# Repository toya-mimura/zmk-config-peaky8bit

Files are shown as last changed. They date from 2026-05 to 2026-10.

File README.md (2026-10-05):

# Peaky 8-bit

A handheld, wireless, 8-key chording keyboard for typing on the go — even while walking.

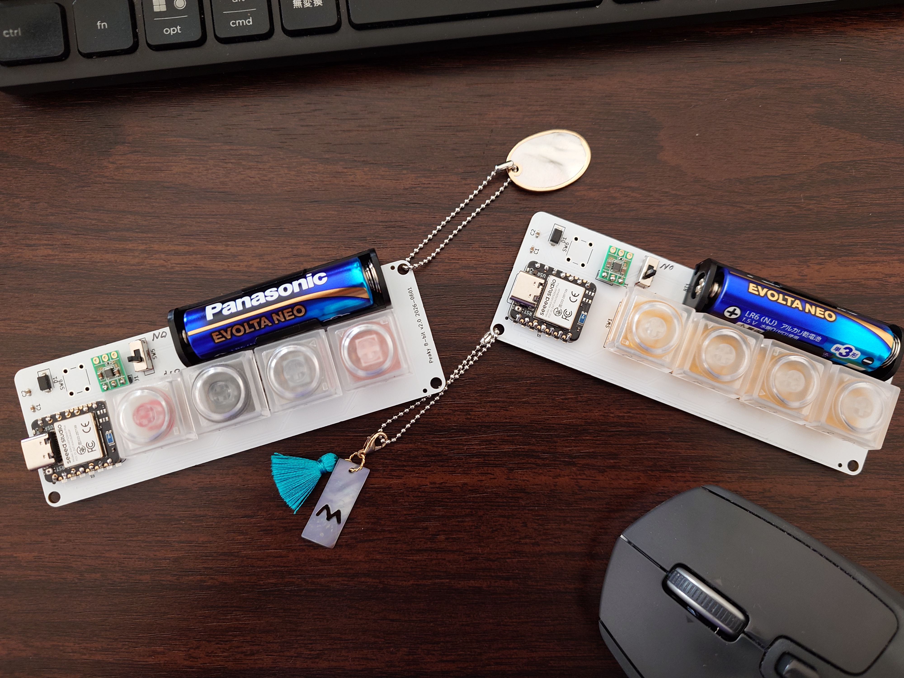
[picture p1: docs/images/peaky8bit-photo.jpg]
Peaky 8-bit prototype


## What is this?

Peaky 8-bit is a split wireless keyboard with just 4 keys per hand (8 total). It uses **binary chord input** — pressing combinations of keys simultaneously — to produce 2⁸ = 256 different outputs. That's enough to cover full English text, numbers, symbols, modifiers, and Bluetooth multi-host switching.

Think of it as a handheld input device shaped like VR controllers, designed to let you type without a desk.

### Want to try chording?
You can test my custom typing logic on any standard QWERTY keyboard (left hand: `ASDF`, right hand: `JKL;`) with my web app:
👉 [Peaky 8-bit Web Typing App](https://typing.peaky8bit.fyi/)

👇Here's the latest keymap status:
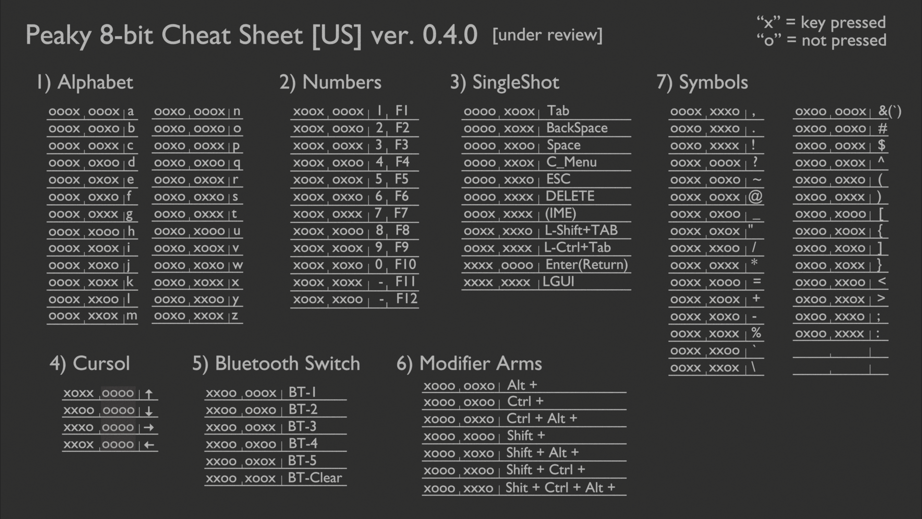
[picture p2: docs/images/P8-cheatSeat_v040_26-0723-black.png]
Latest Keymap


## Status

🚧 **Work in Progress** — This is an active, evolving project. The keymap changes frequently as I refine the layout through daily use. Expect commits to land regularly.

Tagged [releases](../../releases) mark stable snapshots with pre-built `.uf2` firmware files.

## Hardware

| Component | Details |
|---|---|
| MCU | [Seeed Studio XIAO nRF52840 (Plus)](https://www.seeedstudio.com/XIAO-p-5928.html) × 2 |
| Switches | Cherry MX compatible × 8 (4 per hand) |
| Connection | Bluetooth Low Energy (split: left = central, right = peripheral) |
| Power | 1× AAA battery per hand + DC-DC boost converter (no lithium, no charging circuit) |
| PCB | Custom designed, same board for left and right |
| Case | 3D printed (designed in Blender) |

> **Certification:** The XIAO nRF52840 module holds FCC, CE, and Japan TELEC (技適) certifications. No additional wireless certification is required when using it as a pre-certified module.

## Firmware

Built on [ZMK Firmware](https://zmk.dev/) (Zephyr-based, open source).

The entire input system is implemented using ZMK's **combos** feature — each chord pattern maps to a combo that triggers a macro. The keymap currently defines ~180 macros across ~200 combos.

### Building

This is a standard ZMK user config repository. To build:

1. Fork this repository
2. Push to trigger GitHub Actions
3. Download the `.uf2` artifacts from the Actions tab
4. Flash to each XIAO: enter bootloader mode (double-tap RST), drag & drop the `.uf2`

Or build locally with the ZMK toolchain — see [ZMK docs](https://zmk.dev/docs/development/setup/native).

### Keymap

The default keymap targets **US keyboard layout**. The chord-to-character mapping is documented in detail:

- **[keymap_v04.csv](docs/keymap_v04.csv)** — Machine-readable keymap data
- **[gen_keymap.py](docs/gen_keymap.py)** — Python script that generates the ZMK keymap from the CSV
- **[Binary Chords Spec v0.3](docs/binary-chords-spec-v0_3.md)** — Original 256-pattern keymap specification (v0.3, for reference)

#### JIS layout support

If your host PC uses a Japanese keyboard layout (JIS 106/109), regenerate the keymap with the `--layout jis` flag:

```bash
uv run docs/gen_keymap.py docs/keymap_v04.csv --layout jis > boards/shields/peaky8bit/peaky8bit.keymap
```

Then push to rebuild the firmware. The CSV stays the same — `gen_keymap.py` translates the intended characters to the correct HID keycodes for each layout.

### Bluetooth multi-host

Peaky 8-bit supports **5 Bluetooth profiles**, allowing you to pair and switch between up to 5 devices (PCs, phones, tablets, etc.) using chord input:

| Chord | Bit pattern | Action |
|---|---|---|
| `0xC1` | `1100 0001` | Select profile 0 |
| `0xC2` | `1100 0010` | Select profile 1 |
| `0xC3` | `1100 0011` | Select profile 2 |
| `0xC4` | `1100 0100` | Select profile 3 |
| `0xC5` | `1100 0101` | Select profile 4 |
| `0xC9` | `1100 1001` | Clear current profile bond |

To pair a new device: select an empty profile with the corresponding chord, then pair from the new device's Bluetooth settings.

## Repository Structure

```
├── boards/shields/peaky8bit/   # ZMK shield definition
│   ├── peaky8bit.keymap        # Generated keymap (US layout, combos + macros)
│   ├── peaky8bit.conf          # ZMK config (combo limits, etc.)
│   ├── peaky8bit.dtsi          # Common shield definitions
│   ├── peaky8bit_left.overlay  # Left hand (central) GPIO config
│   └── peaky8bit_right.overlay # Right hand (peripheral) GPIO config
├── docs/
│   ├── keymap_v04.csv              # Keymap data (CSV)
│   ├── gen_keymap.py               # Keymap generator (supports --layout us|jis)
│   └── binary-chords-spec-v0_3.md  # Original keymap specification
├── hardware/                   # PCB design files
├── case/                       # 3D printable case (coming soon)
├── build.yaml                  # GitHub Actions build matrix
└── config/west.yml             # ZMK west manifest
```

## How chord input works

Each key is a single bit. Pressing keys simultaneously creates a binary value:

```
Left hand:  [bit7] [bit6] [bit5] [bit4]
Right hand: [bit3] [bit2] [bit1] [bit0]

Example: pressing left-key1 + right-key1 + right-key2
         = bit7 + bit3 + bit2
         = 1000 1100
         = 0x8C
         = Shift+Ctrl modifier arm
```

A single chord can output a letter, a control key, a symbol, or arm a modifier for the next chord.

## Links

- 📝 **Build log & updates:** [toya-works on Substack](https://toyamimura.substack.com/s/peaky-8-bit)
- 💬 **Original announcement:** [r/ErgoMechKeyboards on Reddit](https://www.reddit.com/r/ErgoMechKeyboards/comments/1tkf39y/wip_building_a_handheld_8key_chording_keyboard_to/)
- ☕ **Support this project:** [Buy Me a Coffee](https://buymeacoffee.com/toyaworks)

## PCB Manufacturing

The v2.0 PCBs for this project are manufactured and assembled by **[PCBWay](https://www.pcbway.com/)**. PCBWay handled the board fabrication and SMT soldering for the passive components (bypass caps and diode), with a clean matte-green finish and solid GND fill. The [KiCad plugin](https://www.pcbway.com/blog/News/PCBWay_Plug_In_for_KiCad_3ea6219c.html) made uploading Gerber files and BOM straightforward.

For a detailed walkthrough of the ordering process and unboxing, see the [build log on Substack](https://toyamimura.substack.com/p/peaky-8-bit-the-pcb-from-pcbway-has).

Gerber files, BOM, and pick-and-place files are available in [`hardware/v2.0_pcbway_2026_0601/`](hardware/v2.0_pcbway_2026_0601/). See the readme.txt inside for important notes on which components to include in SMT assembly orders.

## License

- **Hardware** (PCB design, case): [CERN-OHL-P v2](https://ohwr.org/cern_ohl_p_v2.txt)
- **Firmware config** (ZMK keymap, macros): [MIT License](LICENSE)
- **Documentation**: [CC BY-SA 4.0](https://creativecommons.org/licenses/by-sa/4.0/)

## Author

**toya** ([@miumra](https://www.reddit.com/user/miumra) on Reddit)

This is a personal passion project, and I'm learning as I go — progress is slow but steady.

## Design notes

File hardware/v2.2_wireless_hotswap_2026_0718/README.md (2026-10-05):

# Peaky 8-bit v2.2 (Wireless, Hot-swap) — PCB Files

Generated from KiCad on 2026-07-18.
The same PCB is used for both the left and right halves (order 2 boards per keyboard).

## Board specs

| Item | Value |
|---|---|
| Size | 37.55 × 114.97 mm |
| Layers | 2 |
| Thickness | 1.6 mm |

## Files

- `Gerber_wireless_v2.2_0718/` — Gerber and drill files (zip this folder when ordering)
- `bom.csv` — Component list exported from KiCad (with LCSC part numbers for the SMD parts)
- `positions.csv` — Pick-and-place / CPL data (component centers and rotation)
- `designators.csv` — Designator list

## BOM (per board)

Multiply quantities by 2 for a full keyboard (left + right).

| Ref | Part | Qty | Mounting | Source / Notes |
|---|---|---|---|---|
| C1 | Capacitor 0.1 µF, 0603 | 1 | SMD (PCBA) | LCSC [C14663](https://www.lcsc.com/product-detail/C14663.html) |
| C2 | Capacitor 10 µF, 0603 | 1 | SMD (PCBA) | LCSC [C19702](https://www.lcsc.com/product-detail/C19702.html) |
| D1 | Schottky diode SS14, SMA | 1 | SMD (PCBA) | LCSC [C2480](https://www.lcsc.com/product-detail/C2480.html) |
| U1 | Seeed Studio XIAO nRF52840 (Plus) | 1 | Hand-solder | [Seeed Studio](https://www.seeedstudio.com/XIAO-p-5928.html) |
| J1 | DC-DC boost converter module | 1 | Hand-solder | [Akizuki 116116](https://akizukidenshi.com/catalog/g/g116116/) — soldered into the 3-pin through-holes |
| BT1 | AAA battery holder (1 cell) | 1 | Hand-solder | [Akizuki 102670](https://akizukidenshi.com/catalog/g/g102670/) — leads soldered into the 2-pin through-holes |
| SW1–SW4 | Kailh MX hot-swap socket | 4 | Hand-solder | For Cherry MX compatible switches |
| SW5 | Slide switch, SPDT (power) | 1 | Hand-solder | 2.54 mm pitch (e.g. Würth WS-SLTV) |
| SW6 | Tact switch, 6 mm (reset) | 1 | Hand-solder | Optional |

## Ordering the PCB with SMT assembly

The Gerber files are designed so that **C1, C2 and D1 are assembled by the PCB
manufacturer** (e.g. JLCPCB PCBA). Upload the Gerber zip, then `bom.csv` and
`positions.csv` for assembly.

All other components are through-hole and meant to be hand-soldered. Exclude
them from the assembly order (no LCSC part number is listed for them).

## Other parts (per keyboard)

| Part | Qty | Notes |
|---|---|---|
| Key switches (Cherry MX compatible) | 8 | 4 per hand |
| Keycaps (Cherry MX compatible) | 8 | Keycap STL available in [`/case`](../../case) |
| 3D-printed case | 2 | STL: [`case/P8_STL_v2.2_26-0718_hotswap`](../../case/P8_STL_v2.2_26-0718_hotswap) |
| M3 × 20 mm screws + nuts | 8 | 4 per hand |
| AAA alkaline batteries (1.5 V) | 2 | 1 per hand. Rechargeable cells not recommended |

## Tools / requirements

- Soldering iron and solder
- USB Type-C **data** cable (for flashing firmware)
- 3D printer or a printing service
- Firmware: see the [top-level README](../../README.md)

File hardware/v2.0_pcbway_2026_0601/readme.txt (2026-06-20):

# Peaky 8-bit v2.0 — PCB Production Files

Generated from KiCad using the PCBWay plugin on 2026-06-01.

## Files
- Wireless_1.kicad_pcb.zip — Gerber files
- BOM_Wireless_1.kicad_pcb.xls — Full BOM (all components)
- Centroid_Wireless_1_kicad_pcb_revised.zip — Pick-and-place file (C1, C2, D1 only)

## Important: BOM includes ALL components

The BOM exported by the KiCad plugin contains every component on the board.
If you are ordering SMT assembly, you probably only need the following
soldered by the manufacturer:

- C1 (0.1uF, 0603)
- C2 (10uF, 0603)
- D1 (SS14, SMA)

All other components (U1, SW1-6, J1, BT1) are through-hole and intended
to be hand-soldered. Remove them from the BOM before submitting your
assembly order, or specify to your manufacturer which components to assemble.

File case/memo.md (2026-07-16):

These STL files were created using Blender. They are not high-precision CAD models.

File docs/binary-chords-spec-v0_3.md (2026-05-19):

# Binary Chords Keymap Specification v0.3

**改訂日:** 2026-05-19
**v0.2からの主要変更点:**
- キーマップ配置を最新CSV準拠に更新（0x11からかな開始）
- modifier系の割り当てを変更（ZMK標準combos互換のため、すべて2キー以上のchordに変更）
- ZMK実装方針（レイヤー切替方式）を追記
- ローマ字シーケンスを訓令式ベースに統一（Python版custom0405_code.py準拠）

---

## 1. 概要

Binary Chordsは、4キー×2基板（左右）の合計8キーを使用し、各キーの押下状態を1bitとして扱うことで、1回のchord入力で最大256パターン（2^8）の出力を表現するキーボード入力方式である。

**bit配置:**
- 左基板: bit 7-4（MSB側、bit7=左SW1）
- 右基板: bit 3-0（LSB側、bit3=右SW1、bit0=右SW4）

**入力単位:** chord（8キーのうち押下したキーを同時に離した瞬間に確定）

**出力種別:**
- **write:** ローマ字シーケンス送信（IMEがかな変換）
- **key:** 単一HIDキーコード送信
- **keys:** 複数HIDキー同時押下
- **mod:** modifier arm（次のchordを修飾）
- **ime:** IME On/Off
- **None:** 未割り当て

---

## 2. レイヤー構造（ZMK実装）

modifier armは状態機械として表現される。ZMK実装では以下の7レイヤーで管理する：

| レイヤー | 用途 | 遷移元 |
|---|---|---|
| L0 | default（通常） | - |
| L1 | Shift armed | L0からShift arm発火 |
| L2 | Ctrl armed | L0からCtrl arm発火 |
| L3 | Alt armed | L0からAlt arm発火 |
| L4 | Shift+Ctrl armed | L0からShift+Ctrl arm発火 |
| L5 | Shift+Alt armed | L0からShift+Alt arm発火 |
| L6 | Ctrl+Alt armed | L0からCtrl+Alt arm発火 |

**遷移ルール:**
- armed状態でchordを送信すると、自動的にL0に復帰する
- Esc（0x0E）でarmedレイヤーからL0に復帰（キャンセル）
- armed状態の重複は許可しない（Shift armed中にCtrl armedはできない）

---

## 3. modifier系の新割り当て（v0.2からの変更点）

v0.2ではmodifier系を0x01〜0x08（右手単独キーが多い）に割り当てていたが、ZMK標準combosは2キー以上のchord前提のため、以下に変更した：

| bit値 | 物理キー | 意味 |
|---|---|---|
| **0x88** = `1000 1000` | 左SW1 + 右SW1 | **Shift+** |
| **0x84** = `1000 0100` | 左SW1 + 右SW2 | **Ctrl+** |
| **0x82** = `1000 0010` | 左SW1 + 右SW3 | **Alt+** |
| **0x8C** = `1000 1100` | 左SW1 + 右SW1 + 右SW2 | **Shift+Ctrl+** |
| **0x8A** = `1000 1010` | 左SW1 + 右SW1 + 右SW3 | **Shift+Alt+** |
| **0x86** = `1000 0110` | 左SW1 + 右SW2 + 右SW3 | **Ctrl+Alt+** |
| **0x8E** = `1000 1110` | 左SW1 + 右SW1 + 右SW2 + 右SW3 | **Shift+Ctrl+Alt+** |

**論理性:**
- 左SW1（bit7=「左の親指」）を押すと「modifier mode」
- 右手のbit値で modifier の組み合わせを指定：
  - 右SW1（bit3） = Shiftフラグ
  - 右SW2（bit2） = Ctrlフラグ
  - 右SW3（bit1） = Altフラグ
- 上記の OR で複合 modifier を表現

**元の0x01〜0x08は予約**（将来のメディアキー、マウス操作等のために確保）。

---

## 4. ローマ字表記スタイル

Python版（custom0405_code.py）に準拠。**訓令式ベース、最短入力数優先**。

| かな | ローマ字 | 備考 |
|---|---|---|
| し / じ | si / zi | 訓令式 |
| ち / ぢ | ti / di | 訓令式 |
| つ / づ / っ | tu / du / xtu | 訓令式 |
| ふ / ぶ / ぷ | hu / bu / pu | 訓令式 |
| ん | nn | 後続文字混同回避のため2文字 |
| を | wo | |
| ゃゅょゎ | xya / xyu / xyo / xwa | x接頭辞 |
| ぁぃぅぇぉ | xa / xi / xu / xe / xo | x接頭辞 |

**前提:** Windows MS-IME のローマ字入力モード（または同等の動作をするGoogle日本語入力等）。

---

## 5. キーマップ表（256パターン）

凡例:
- `write:xxx` = 文字列xxxをローマ字シーケンスとして送信
- `key:XXX` = HIDキーコードXXXを単発送信
- `keys:K1+K2` = 複数キー同時押下
- `mod:Shift` = Shift armedレイヤーへ遷移
- `ime` = IME On/Off切替
- `(None)` = 未割り当て

### 0x00 - 0x0F（システム・制御）

| Hex | bit | layer1 | withShift | withCtrl | 備考 |
|---|---|---|---|---|---|
| 0x00 | `0000 0000` | (None) | (None) | (None) | 何も押されていない |
| 0x01-0x08 | - | (reserved) | (reserved) | (reserved) | v0.3で予約 |
| 0x09 | `0000 1001` | key:TAB | | | |
| 0x0A | `0000 1010` | key:LGUI | | | superkey/Windowsキー |
| 0x0B | `0000 1011` | key:BSPC | | | BackSpace |
| 0x0C | `0000 1100` | key:SPACE | | | |
| 0x0D | `0000 1101` | key:RET | | | Enter |
| 0x0E | `0000 1110` | key:ESC | | | armed状態ならキャンセル |
| 0x0F | `0000 1111` | key:DEL | | | Delete |

### 0x10 - 0x1F（数字1・あ行・記号）

| Hex | bit | layer1 | withShift | withCtrl |
|---|---|---|---|---|
| 0x10 | `0001 0000` | write:1 | key:F1 | |
| 0x11 | `0001 0001` | write:a | | write:xa |
| 0x12 | `0001 0010` | write:i | | write:xi |
| 0x13 | `0001 0011` | write:u | | write:xu |
| 0x14 | `0001 0100` | write:e | | write:xe |
| 0x15 | `0001 0101` | write:o | | write:xo |
| 0x16 | `0001 0110` | write:! | write:! | |
| 0x17 | `0001 0111` | write:, | write:, | |
| 0x18 | `0001 1000` | write:. | write:. | |
| 0x19 | `0001 1001` | write:? | write:? | |
| 0x1A | `0001 1010` | write:~ | write:~ | |
| 0x1B | `0001 1011` | write:@ | write:@ | |
| 0x1C | `0001 1100` | write:_ | write:_ | |
| 0x1D | `0001 1101` | write:" | write:" | |
| 0x1E | `0001 1110` | write:& | write:& | |
| 0x1F | `0001 1111` | ime | ime | |

### 0x20 - 0x2F（数字2・か行・記号）

| Hex | bit | layer1 | withShift | withCtrl |
|---|---|---|---|---|
| 0x20 | `0010 0000` | write:2 | key:F2 | |
| 0x21 | `0010 0001` | write:ka | write:ga | |
| 0x22 | `0010 0010` | write:ki | write:gi | |
| 0x23 | `0010 0011` | write:ku | write:gu | |
| 0x24 | `0010 0100` | write:ke | write:ge | |
| 0x25 | `0010 0101` | write:ko | write:go | |
| 0x26 | `0010 0110` | write:# | write:# | |
| 0x27 | `0010 0111` | write:$ | write:$ | |
| 0x28 | `0010 1000` | write:% | write:% | |
| 0x29 | `0010 1001` | (None) | | |
| 0x2A | `0010 1010` | write:' | write:' | |
| 0x2B | `0010 1011` | (None) | | |
| 0x2C | `0010 1100` | write:^ | write:^ | |
| 0x2D | `0010 1101` | write:` | write:` | |
| 0x2E | `0010 1110` | write:\\ | write:\\ | |
| 0x2F | `0010 1111` | (None) | | |

### 0x30 - 0x3F（数字3・さ行・記号）

| Hex | bit | layer1 | withShift | withCtrl |
|---|---|---|---|---|
| 0x30 | `0011 0000` | write:3 | key:F3 | |
| 0x31 | `0011 0001` | write:sa | write:za | |
| 0x32 | `0011 0010` | write:si | write:zi | |
| 0x33 | `0011 0011` | write:su | write:zu | |
| 0x34 | `0011 0100` | write:se | write:ze | |
| 0x35 | `0011 0101` | write:so | write:zo | |
| 0x36 | `0011 0110` | write:/ | write:/ | |
| 0x37 | `0011 0111` | write:* | write:* | |
| 0x38 | `0011 1000` | write:= | write:= | |
| 0x39 | `0011 1001` | write:+ | write:+ | |
| 0x3A | `0011 1010` | write:- | write:- | |
| 0x3B-0x3D | - | (None) | | |
| 0x3E | `0011 1110` | keys:LSHIFT+TAB | | | not modifier（その場でShift+Tab送信） |
| 0x3F | `0011 1111` | keys:LCTRL+TAB | | | not modifier |

### 0x40 - 0x4F（数字4・た行・記号）

| Hex | bit | layer1 | withShift | withCtrl |
|---|---|---|---|---|
| 0x40 | `0100 0000` | write:4 | key:F4 | |
| 0x41 | `0100 0001` | write:ta | write:da | |
| 0x42 | `0100 0010` | write:ti | write:di | |
| 0x43 | `0100 0011` | write:tu | write:du | write:xtu |
| 0x44 | `0100 0100` | write:te | write:de | |
| 0x45 | `0100 0101` | write:to | write:do | |
| 0x46 | `0100 0110` | write:( | write:( | |
| 0x47 | `0100 0111` | write:) | write:) | |
| 0x48 | `0100 1000` | write:[ | write:[ | |
| 0x49 | `0100 1001` | write:{ | write:{ | |
| 0x4A | `0100 1010` | write:] | write:] | |
| 0x4B | `0100 1011` | write:} | write:} | |
| 0x4C | `0100 1100` | write:< | write:< | |
| 0x4D | `0100 1101` | write:> | write:> | |
| 0x4E | `0100 1110` | write:; | write:; | |
| 0x4F | `0100 1111` | write:: | write:: | |

### 0x50 - 0x5F（数字5・な行）

| Hex | bit | layer1 | withShift | withCtrl |
|---|---|---|---|---|
| 0x50 | `0101 0000` | write:5 | key:F5 | |
| 0x51 | `0101 0001` | write:na | | |
| 0x52 | `0101 0010` | write:ni | | |
| 0x53 | `0101 0011` | write:nu | | |
| 0x54 | `0101 0100` | write:ne | | |
| 0x55 | `0101 0101` | write:no | | |
| 0x56-0x5F | - | (None) | | |

### 0x60 - 0x6F（数字6・は行）

| Hex | bit | layer1 | withShift | withCtrl |
|---|---|---|---|---|
| 0x60 | `0110 0000` | write:6 | key:F6 | |
| 0x61 | `0110 0001` | write:ha | write:ba | write:pa |
| 0x62 | `0110 0010` | write:hi | write:bi | write:pi |
| 0x63 | `0110 0011` | write:hu | write:bu | write:pu |
| 0x64 | `0110 0100` | write:he | write:be | write:pe |
| 0x65 | `0110 0101` | write:ho | write:bo | write:po |
| 0x66-0x6F | - | (None) | | |

### 0x70 - 0x7F（数字7・ま行）

| Hex | bit | layer1 | withShift | withCtrl |
|---|---|---|---|---|
| 0x70 | `0111 0000` | write:7 | key:F7 | |
| 0x71 | `0111 0001` | write:ma | | |
| 0x72 | `0111 0010` | write:mi | | |
| 0x73 | `0111 0011` | write:mu | | |
| 0x74 | `0111 0100` | write:me | | |
| 0x75 | `0111 0101` | write:mo | | |
| 0x76-0x7F | - | (None) | | |

### 0x80 - 0x8F（数字8・や行・modifier）

| Hex | bit | layer1 | withShift | withCtrl |
|---|---|---|---|---|
| 0x80 | `1000 0000` | write:8 | key:F8 | |
| 0x81 | `1000 0001` | write:ya | | write:xya |
| **0x82** | `1000 0010` | **mod:Alt** | | | **新規（v0.3）** |
| 0x83 | `1000 0011` | write:yu | | write:xyu |
| **0x84** | `1000 0100` | **mod:Ctrl** | | | **新規（v0.3）** |
| 0x85 | `1000 0101` | write:yo | | write:xyo |
| **0x86** | `1000 0110` | **mod:Ctrl+Alt** | | | **新規（v0.3）** |
| 0x87 | `1000 0111` | (None) | | |
| **0x88** | `1000 1000` | **mod:Shift** | | | **新規（v0.3）** |
| 0x89 | `1000 1001` | (None) | | |
| **0x8A** | `1000 1010` | **mod:Shift+Alt** | | | **新規（v0.3）** |
| 0x8B | `1000 1011` | (None) | | |
| **0x8C** | `1000 1100` | **mod:Shift+Ctrl** | | | **新規（v0.3）** |
| 0x8D | `1000 1101` | (None) | | |
| **0x8E** | `1000 1110` | **mod:Shift+Ctrl+Alt** | | | **新規（v0.3）** |
| 0x8F | `1000 1111` | (None) | | |

### 0x90 - 0x9F（数字9・ら行）

| Hex | bit | layer1 | withShift | withCtrl |
|---|---|---|---|---|
| 0x90 | `1001 0000` | write:9 | key:F9 | |
| 0x91 | `1001 0001` | write:ra | | |
| 0x92 | `1001 0010` | write:ri | | |
| 0x93 | `1001 0011` | write:ru | | |
| 0x94 | `1001 0100` | write:re | | |
| 0x95 | `1001 0101` | write:ro | | |
| 0x96-0x9F | - | (None) | | |

### 0xA0 - 0xAF（数字0・わ行・ん）

| Hex | bit | layer1 | withShift | withCtrl |
|---|---|---|---|---|
| 0xA0 | `1010 0000` | write:0 | key:F10 | |
| 0xA1 | `1010 0001` | write:wa | | write:xwa |
| 0xA2 | `1010 0010` | (None) | | |
| 0xA3 | `1010 0011` | write:wo | | |
| 0xA4 | `1010 0100` | (None) | | |
| 0xA5 | `1010 0101` | write:nn | | |
| 0xA6-0xAF | - | (None) | | |

### 0xB0 - 0xBF（矢印↑・拡張領域）

| Hex | bit | layer1 | withShift | withCtrl |
|---|---|---|---|---|
| 0xB0 | `1011 0000` | key:UP | key:F11 | |
| 0xB1-0xBF | - | (None) | | |

### 0xC0 - 0xCF（矢印↓・拡張領域）

| Hex | bit | layer1 | withShift | withCtrl |
|---|---|---|---|---|
| 0xC0 | `1100 0000` | key:DOWN | key:F12 | |
| 0xC1-0xCF | - | (None) | | |

### 0xD0 - 0xDF（矢印←・拡張領域）

| Hex | bit | layer1 | withShift | withCtrl |
|---|---|---|---|---|
| 0xD0 | `1101 0000` | key:LEFT | | |
| 0xD1-0xDF | - | (None) | | |

### 0xE0 - 0xEF（矢印→・アルファベットa-o）

| Hex | bit | layer1 | withShift | withCtrl |
|---|---|---|---|---|
| 0xE0 | `1110 0000` | key:RIGHT | | |
| 0xE1 | `1110 0001` | write:a | write:A | |
| 0xE2 | `1110 0010` | write:b | write:B | |
| 0xE3 | `1110 0011` | write:c | write:C | |
| 0xE4 | `1110 0100` | write:d | write:D | |
| 0xE5 | `1110 0101` | write:e | write:E | |
| 0xE6 | `1110 0110` | write:f | write:F | |
| 0xE7 | `1110 0111` | write:g | write:G | |
| 0xE8 | `1110 1000` | write:h | write:H | |
| 0xE9 | `1110 1001` | write:i | write:I | |
| 0xEA | `1110 1010` | write:j | write:J | |
| 0xEB | `1110 1011` | write:k | write:K | |
| 0xEC | `1110 1100` | write:l | write:L | |
| 0xED | `1110 1101` | write:m | write:M | |
| 0xEE | `1110 1110` | write:n | write:N | |
| 0xEF | `1110 1111` | write:o | write:O | |

### 0xF0 - 0xFF（Enter・アルファベットp-z）

| Hex | bit | layer1 | withShift | withCtrl |
|---|---|---|---|---|
| 0xF0 | `1111 0000` | key:RET | | |
| 0xF1 | `1111 0001` | write:p | write:P | |
| 0xF2 | `1111 0010` | write:q | write:Q | |
| 0xF3 | `1111 0011` | write:r | write:R | |
| 0xF4 | `1111 0100` | write:s | write:S | |
| 0xF5 | `1111 0101` | write:t | write:T | |
| 0xF6 | `1111 0110` | write:u | write:U | |
| 0xF7 | `1111 0111` | write:v | write:V | |
| 0xF8 | `1111 1000` | write:w | write:W | |
| 0xF9 | `1111 1001` | write:x | write:X | |
| 0xFA | `1111 1010` | write:y | write:Y | |
| 0xFB | `1111 1011` | write:z | write:Z | |
| 0xFC-0xFF | - | (None) | | |

---

## 6. 集計

| 種別 | パターン数 |
|---|---|
| かな清音（あ行〜わ行+ん） | 46 |
| かな濁音（withShift） | 25 |
| かな半濁音・小書き（withCtrl） | 15 |
| 数字（0〜9） | 10 |
| F1〜F10（withShift） | 10 |
| アルファベット小文字（a〜z） | 26 |
| アルファベット大文字（withShift） | 26 |
| 記号（layer1） | 25 |
| 記号（withShift、ほぼ同記号） | 25 |
| 矢印 | 4 |
| 制御キー（Tab/BS/Space/Enter/Esc/Delete/superkey/Shift+Tab/Ctrl+Tab） | 9 |
| modifier arm（mod:* 系） | 7 |
| IME | 1 |
| **総アクション数** | **約229** |
| **総combo数（レイヤー別重複考慮後）** | 約350-400 |

---

## 7. ZMK実装方針

### 7.1 macro 命名規則

- `m_h_<hex>`: layer1 の動作（例: `m_h_21` = 「か」を送信するmacro）
- `m_s_<hex>`: withShift の動作
- `m_c_<hex>`: withCtrl の動作
- `m_arm_shift`, `m_arm_ctrl` 等: modifier arm

### 7.2 macro の末尾処理

armedレイヤー（L1〜L6）で発火するmacroは、末尾で必ず `<&to 0>` を追加する（L0復帰）。
modifier付きHID送信もmacro内で完結させる（Shift押下→キー送信→Shift解放→L0復帰）。

### 7.3 Esc（キャンセル）の扱い

0x0Eを全armedレイヤー（L1〜L6）で受けて、L0に戻すcomboを追加する。
L0で0x0Eを押した場合は通常のEscキー送信。

### 7.4 IME（0x1F）の扱い

Windows MS-IMEを前提に、`key:LANG1`（Henkan）または `kp INT5`（半角/全角）を送信。
要検証：実機でどのHIDコードがIME On/Offに対応するか確認。

### 7.5 CONFIG値

```
CONFIG_ZMK_COMBO_MAX_KEYS_PER_COMBO=8
CONFIG_ZMK_COMBO_MAX_COMBOS_PER_KEY=128  # 要検証、足りなければ256に
CONFIG_ZMK_COMBO_MAX_PRESSED_COMBOS=8
CONFIG_ZMK_KEYMAP_LAYERS_STATE_CHANGED=y  # debug用
```

---

## 8. 既知の制約

- **同じkey-positionsを共有するcomboの最大数:** ZMK CONFIG_ZMK_COMBO_MAX_COMBOS_PER_KEY で制限される。各キーから見て関与するcombo数を計算し、適切に設定する必要あり。
- **chord判定タイミング:** ZMKのcomboは「最初のキー押下から timeout-ms 以内に key-positions が揃う」と発火。Python版の「リリース時にスナップショット」とは厳密には異なる。実機で違和感がないか要確認。
- **layer-aware combos:** ZMKは `layers = <N>` でレイヤー指定combo可能（v3.5以降）。本実装はv0.3 manifest を使用。

---

## 9. v0.2 → v0.3 移行ガイド

| 項目 | v0.2 | v0.3 |
|---|---|---|
| Shift+ | 0x01（右SW4） | 0x88（左SW1+右SW1） |
| Ctrl+ | 0x05（右SW2+SW4） | 0x84（左SW1+右SW2） |
| Alt+ | 0x08（右SW1） | 0x82（左SW1+右SW3） |
| Shift+Ctrl+ | 0x02 | 0x8C |
| Shift+Alt+ | 0x03 | 0x8A |
| Ctrl+Alt+ | 0x06 | 0x86 |
| ローマ字 | 多様 | 訓令式に統一（si/ti/tu/hu/nn） |

**有線版（Python）との関係:**
v0.3 仕様は無線版（ZMK）の制約に合わせた更新であり、有線版（custom0405_code.py）は v0.2 のままで動作する。有線版を v0.3 に追従するかは別途判断。

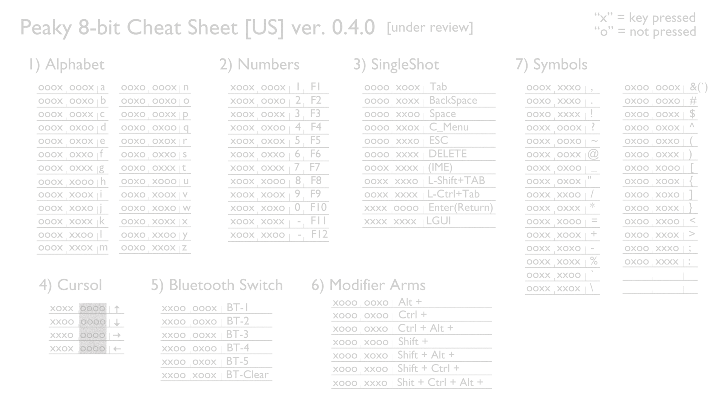
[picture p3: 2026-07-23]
docs/images/P8-cheatSeat_v040_26-0723-alphaWhite.png

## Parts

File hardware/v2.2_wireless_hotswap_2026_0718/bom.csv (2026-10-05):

Designator | Footprint | Quantity | Value | LCSC Part #
BT1 | PinHeader_1x02_P2.54mm_Vertical | 1 | Battery_Cell
C1 | 0603 | 1 | 0.1uF | C14663
C2 | 0603 | 1 | 10uF | C19702
D1 | D_SMA | 1 | SS14 | C2480
J1 | PinHeader_1x03_P2.54mm_Vertical | 1 | Conn_01x03
SW1, SW2, SW3, SW4 | SW_Hotswap_Kailh_MX_1.00u | 4 | SW_Push
SW5 | SW_Slide-03_Wuerth-WS-SLTV_10x2.5x6.4_P2.54mm | 1 | SW_SPDT
SW6 | SW_PUSH_6mm | 1 | SW_Push
U1 | XIAO-nRF52840-DIP | 1 | XIAO-nRF52840-DIP

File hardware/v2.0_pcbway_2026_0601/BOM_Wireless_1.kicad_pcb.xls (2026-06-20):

Designator | Quantity | Value | Footprint | Package | MPN | DNP | Mount_Type | Description | KiLib_Generator | Sim.Device | Sim.Type | Sim.Pins
BT1 | 1 | Battery_Cell | PinHeader_1x02_P2.54mm_Vertical |  |  |  | tht | Single-cell battery | connector/pin_header_socket | V | DC | 1=+ 2=-
C1 | 1 | 0.1uF | C_0603_1608Metric |  |  |  | smt | Unpolarized capacitor | SMD_2terminal_chip_molded
C2 | 1 | 10uF | C_0603_1608Metric |  |  |  | smt | Unpolarized capacitor | SMD_2terminal_chip_molded
D1 | 1 | SS14 | D_SMA |  |  |  | smt | Schottky diode
J1 | 1 | Conn_01x03 | PinHeader_1x03_P2.54mm_Vertical |  |  |  | tht | Generic connector, single row, 01x03, script generated (kicad-library-utils/schlib/autogen/connector/) | connector/pin_header_socket
SW1, SW2, SW3, SW4 | 4 | SW_Push | SW_Cherry_MX_1.00u_PCB |  |  |  | tht | Push button switch, generic, two pins
SW5 | 1 | SW_SPDT | SW_Slide-03_Wuerth-WS-SLTV_10x2.5x6.4_P2.54mm |  |  |  | tht | Switch, single pole double throw
SW6 | 1 | SW_Push | SW_PUSH_6mm |  |  |  | tht | Push button switch, generic, two pins
U1 | 1 | XIAO-nRF52840-DIP | XIAO-nRF52840-DIP |  |  |  | smt

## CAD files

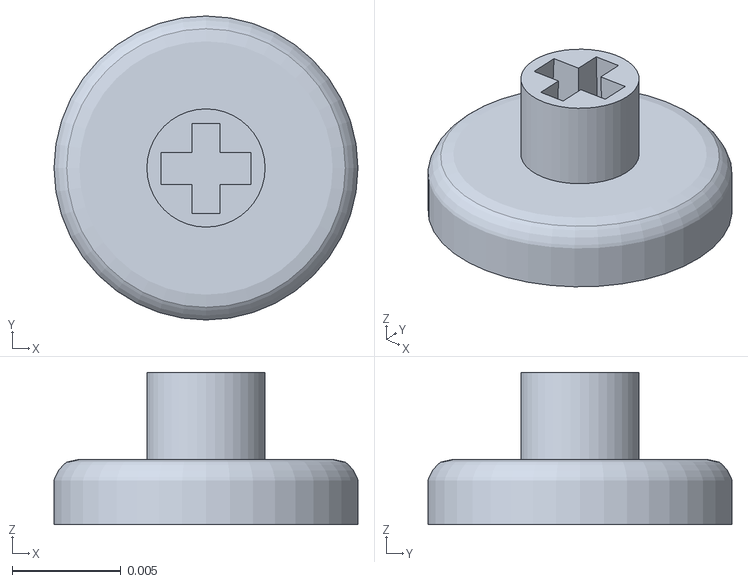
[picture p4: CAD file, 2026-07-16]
case/P8_General-KeyCap_v1.0.stl
0.014 x 0.014 x 0.007

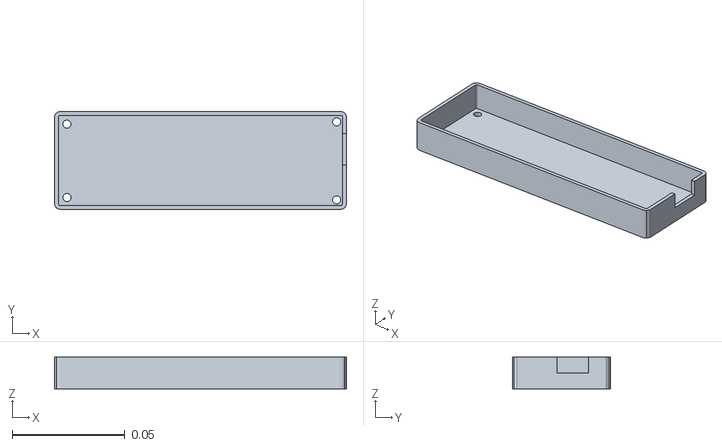
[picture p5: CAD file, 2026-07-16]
case/P8_STL_v1.0_wired/p8_v10_26-0502_1_Base.stl
0.129 x 0.0434 x 0.014

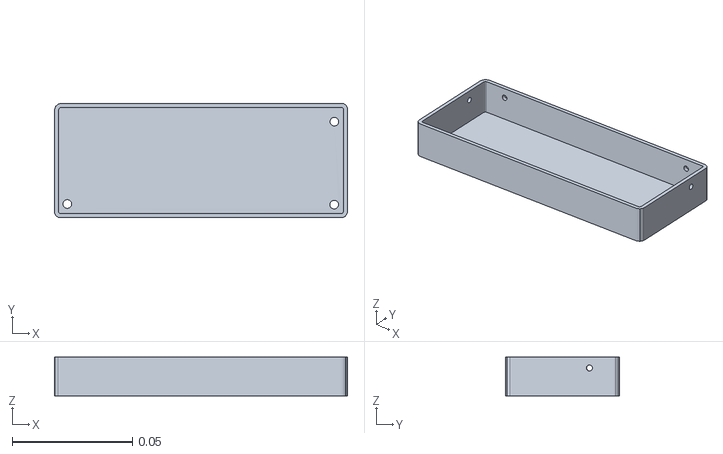
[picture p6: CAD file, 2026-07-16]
case/P8_STL_v2.0_AA-batteryVersion/p8_v20_26-0601_1_Base.stl
0.122 x 0.0475 x 0.016

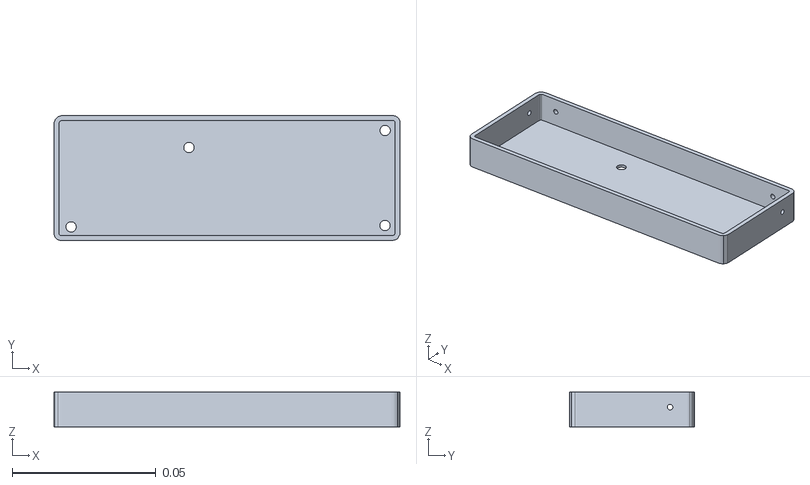
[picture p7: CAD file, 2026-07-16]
case/P8_STL_v2.1_26-0616_AAA-batteryVersion/p8_v21_26-0616_1_Base.stl
0.12 x 0.0434 x 0.012

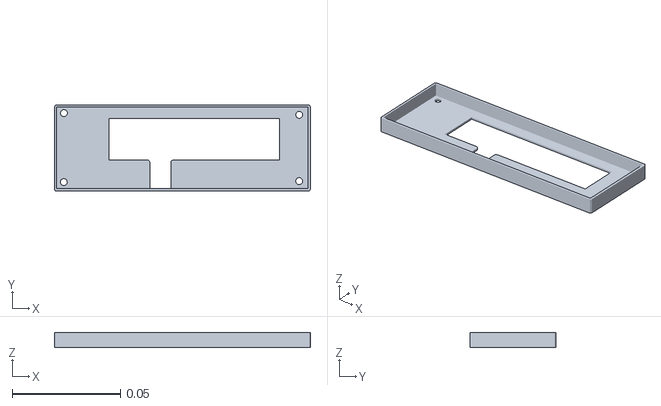
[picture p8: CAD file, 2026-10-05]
case/P8_STL_v2.2_26-0718_hotswap/p8-v22_26-1005_4_cover.stl
0.118 x 0.0395 x 0.007

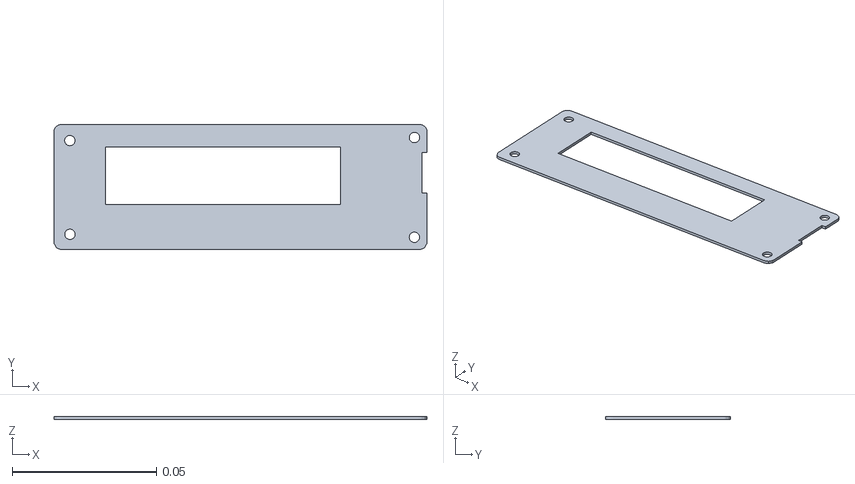
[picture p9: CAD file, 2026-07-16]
case/P8_STL_v1.0_wired/p8_v10_26-0502_2_cover.stl
0.129 x 0.0434 x 0.000999

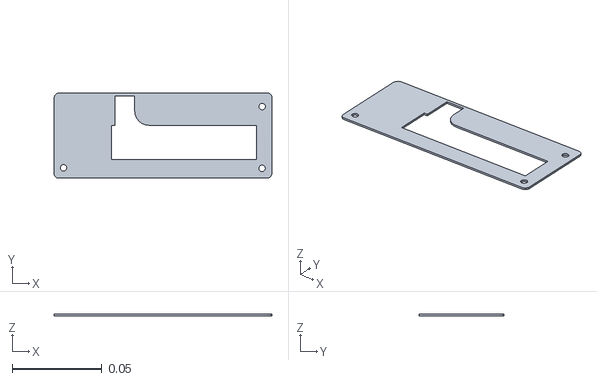
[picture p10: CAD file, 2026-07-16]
case/P8_STL_v2.0_AA-batteryVersion/p8_v20_26-0601_3_Spacer.stl
0.122 x 0.0475 x 0.00105

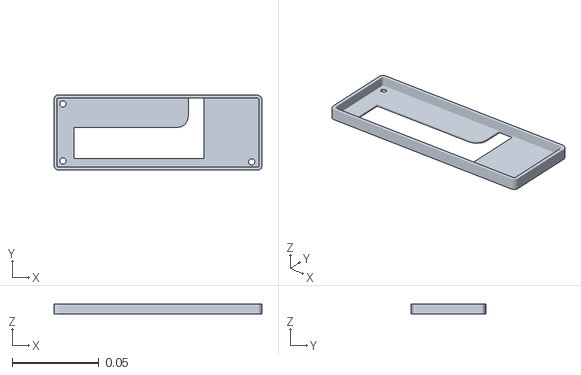
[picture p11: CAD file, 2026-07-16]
case/P8_STL_v2.1_26-0616_AAA-batteryVersion/p8_v21_26-0616_2_Cover.stl
0.12 x 0.0434 x 0.006

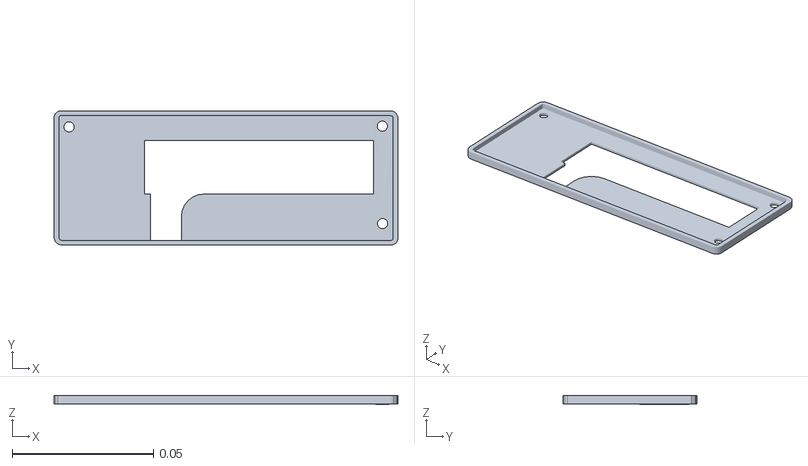
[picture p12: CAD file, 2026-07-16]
case/P8_STL_v2.0_AA-batteryVersion/p8_v20_26-0601_2_Cover.stl
0.122 x 0.0475 x 0.00305

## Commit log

2026-05-11 Fix devicetree syntax: add missing < in map property
2026-05-19 Fix: change Shift arm chord from 0x01 to 0x88 (avoid single-key combo)
2026-05-19 Add v0.3 spec and keymap generation tooling
    [keymap_v03.csv]
2026-06-14 Add Bluetooth selection buttons to keymap
    Added new Bluetooth selection buttons to the keymap.
    [keymap_v03.csv]
2026-06-16 英語優先キーマップ（v04）
    [keymap_v04.csv]
2026-06-20 garber file and BOM list for v2.0 (PCBWay version)
    [BOM_Wireless_1.kicad_pcb.xls]
2026-06-20 garber file and BOM list for v2.0-PCBWay version
    [BOM_Wireless_1.kicad_pcb.xls]
2026-06-20 Enhance PCB manufacturing details in README
    Updated PCB manufacturing section with details on v2.0 PCBs, including sponsorship by PCBWay, ordering process, and file availability.
2026-06-20 Update link in PCB manufacturing section
2026-06-27 Add LCTRL key combinations for letters in keymap
    [keymap_v04.csv]
2026-06-28 Update keymap with function keys and reorganize
    Reorganized key mappings and restored function keys.
    [keymap_v04.csv]
2026-07-16 Add memo about STL files created with Blender
2026-07-16 added Peaky 8-bit case for ver 1.0
    [p8_v10_26-0502_1_Base.stl, p8_v10_26-0502_2_cover.stl]
2026-07-16 added Peaky 8-bit case for ver 2.0
    [p8_v20_26-0601_1_Base.stl, p8_v20_26-0601_2_Cover.stl, p8_v20_26-0601_3_Spacer.stl]
2026-07-16 added case stl for Peaky 8-bit ver2.1
    [p8_v21_26-0616_1_Base.stl, p8_v21_26-0616_2_Cover.stl]
2026-07-16 added p8 case for v2.1
    [p8_v21_26-0616_1_Base.stl, p8_v21_26-0616_2_Cover.stl]
2026-07-16 added keycap STL
    [P8_General-KeyCap_v1.0.stl]
2026-07-19 Remove duplicate LGUI entry and add at the end
    [keymap_v04.csv]
2026-07-20 Disable BLE battery level notifications
    Disable BLE battery level notification for AA battery operation.
2026-07-24 Update Bluetooth configuration for stability and power
2026-10-05 キーキャップに合わせてカバーの穴を1mmほど拡張。
    [p8-v22_26-1005_4_cover.stl]
2026-10-05 スペル訂正（Garber⇒Gerber）
    [Wireless_1-B_Cu.gbr, Wireless_1-B_Mask.gbr, Wireless_1-B_Paste.gbr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]
2026-10-05 Change power source from AA to AAA batteries
    Updated power requirements to use AAA batteries with a DC-DC boost converter.
2026-10-12 Update print statement from 'Hello' to 'Goodbye'
